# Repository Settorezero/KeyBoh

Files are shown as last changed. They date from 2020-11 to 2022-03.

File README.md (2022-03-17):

# KeyBoh

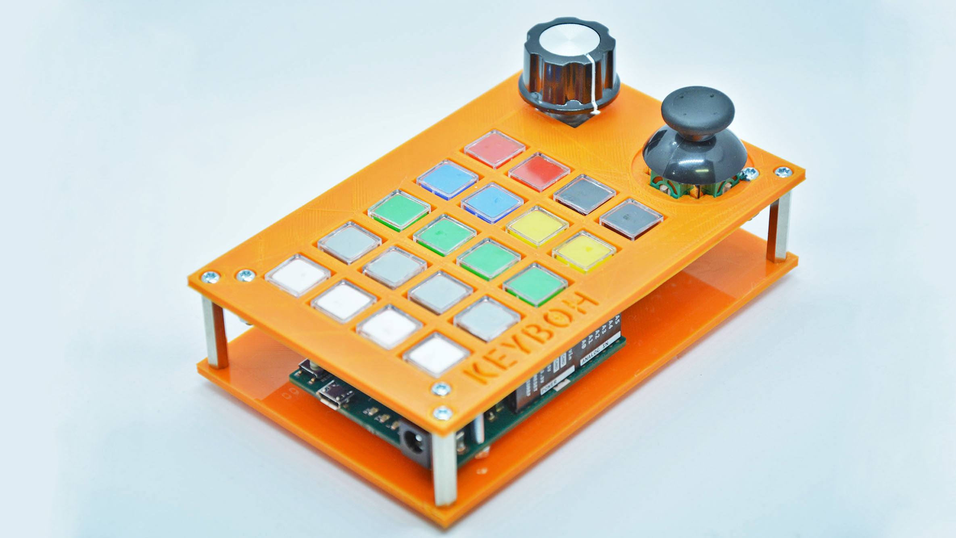
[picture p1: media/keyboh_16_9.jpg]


KeyBoh is an Arduino Leonardo shield for making customizable, cheap, USB keyboards. We love to use the [NicoHood HID Project library](https://github.com/NicoHood/HID) for interfacing the whole thing to a Computer. It's very cheap because uses commonly available 12x12 tactile switches.

## PCB  
PCBWay has the project ready to be manufactured and shipped. Making the PCB on PCBWay will support our work!  
You need to subscribe to PCBWay first using [this invite link](https://www.pcbway.com/setinvite.aspx?inviteid=355653&from=settorezero2020). Then you'll have a bonus of $5 for PCB Manufacturing.   
Once subscribed to PCBWay you can let them make you the PCB [from the shared project page](https://www.pcbway.com/project/shareproject/KeyBoh_Shield.html).
[Gerbers](./gerbers) are provided anyway.

## Enclosure
In the [STL folder](./stl) are located the two panels you can 3Dprint by yourself. Then you can assemble the Keyboh as showed in the pictures using 4x 24mm F/F  and 4x M/F 6mm hex spacers + 12x M3 6mm screws and 4 3M bolts.

## Code examples
See in the [Arduino folder](./arduino) for code examples. We're currently working to a multi-predefined configurable keyset for various applications, so stay tuned.  

## Informations
See the [NicoHood HID Project library](https://github.com/NicoHood/HID) for knowing how library works and example.
In the [keys.txt](./docs/keys.txt) document are reported the names for the keys of the keyboard as used by NicoHood library.

## Connection table
(To do)
In the meanwhile look at schematic in the [docs folder](./docs)

## Can I use keyboh with other boards?
Keyboh is designed for the Arduino __Leonardo__ using his own USB features for making USB devices you can use on the computer or any device recognizes HID devices (even if on cellphone).

### Keyboh on Arduino UNO ?
You can use Keyboh on the Arduino UNO if you want to control remote devices through the UART: you can connect an external device simply connecting the UART using wires or you can attach a Bluetooth or an XBee module, or an ESP8266 but be always aware of the voltage levels! There is the possibility to have a voltage divider only on the Arduino RX but connecting an ESP8266 requires a voltage divider on the TX.  

You can use Keyboh on the Arduino UNO also for USB communication using the [HoodLoader by NicoHood](https://github.com/NicoHood/HoodLoader2). This project is made for reprogramming the 16U2, used on the UNO as serial/USB bridge, and use it for USB custom purposes. We've still not used that feature so please read the documentation of this library.

Since the Leonardo has separate `SDA` and `SCL` lines while the UNO has `SDA` and `SCL` shared with `A4` and `A5`, using the shield on the UNO will make not available I2C lines, or you may not use the joystick (connected to A4 and A5) freeing those two pins for using them for I2C.  

### Keyboh on other boards
You can use the shield on other development boards connecting wires on pads: the silkscreen will help a lot.  
You can also saw off the PCB part with encoder and joystick: a part of soldering pads will be anyway available for reconnecting the two separate pcbs or for connecting them through wires.

## Warnings!!
Since keymatrix is implemented __without protection diodes on pushbuttons__, is no safe press more than 1 button on the same row at a time: this bring to a momentary short-circuit since 2 or more columns are connected together. Usually this is not a big problem since the duration of the short is very small due to column scan, but is better not doing this. In the next revision we'll add the protection diodes.

## Bad Coding leads to problems!
First of all: Always remember to put a `Keyboard.releaseALL()` or `Keyboard.relese([KEY])` after `Keyboard.press` instructions or the keys will remain pressed forever causing a lot of problems!

A very big problem is this: you write some wrong instructions so the keyboard cycles some keys indefinitely (ore some keys are always pressed) and then, since those keys affects the Arduino IDE functions, you may be not able to reprogram the board. In this case a thing you can do is detach the Arduino Leonardo, then see in the Control Panel which devices are connected, then you attach the Leonardo and you will see new devices (example: _HID Keyboard_), in the panel you can try to disinstall the new device (<kbd>Mouse right click</kbd> - <kbd>Uninstall</kbd>) but you need to do this very fast.

In worst cases you can reprogram the Leonardo with a clean sketch on the ISP connector using another Arduino as ISP programmer.

Another problem can be _board not recognized_ from Arduino IDE even if the board is working and the selected serial port is right. In this case try to disconnect and reconnect the USB cable or pressing the Leonardo <kbd>reset</kbd> button after you've pressed the IDE button for the sketch upload.

## Notes for an ipothetical next PCB revision
- Add protection diodes on keymatrix switches
- Add circuitry for hardware debounce, on the encoder mainly
- Add voltage divider also on UART TX
- Use the Arduino micro instead of Leonardo (more compact) ?

## Links
- [more pictures of KeyBoh](https://photos.app.goo.gl/CL2jDvoLArWxuAqx8)
- [video example: usage on Photoshop](https://www.instagram.com/tv/CJuXJ9UKTim/)
- [video example: usage with commercial robot](https://www.instagram.com/p/CJzhHA2K29V/)

## Sharings
Since we love when others share our projects, here are linked pages who shared the project.  
Those links can be useful since people make also questions commenting on social posts and we try to give answers directly.

- [Arduino on IG](https://www.instagram.com/p/CIPJXs_j-tg/)
- [Arduino on TW](https://twitter.com/arduino/status/1333078330598363136)
- [Arduino on FB](https://www.facebook.com/official.arduino/posts/5567229216636685)
- [PCBWay on IG](https://www.instagram.com/p/CINa9Nnra6t/)
- [PCBWay on TW](https://twitter.com/PCBWayOfficial/status/1333344888537026561)
- [Microchip on IG](https://www.instagram.com/p/CIRuX1qnB_U/)
- [Microchip on TW](https://twitter.com/MicrochipMakes/status/1333442492117737475)
- [Microchip on FB](https://www.facebook.com/MicrochipMakes/posts/3820599841292022)
- [Hackster](https://www.hackster.io/news/keyboh-is-an-open-source-arduino-leonardo-shield-for-making-custom-usb-keyboards-208a930cc3f5)

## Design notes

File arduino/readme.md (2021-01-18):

## KeyBoh Firmwares

[Keytest](./keytest)  
Output values of buttons, encoder and thumbstick on the serial port. 
Only for testing purposes, to be sure every component on PCB works. So this sketch has no HID functions.

[Example](./example)  
Thumbstick and encoder used as mouse functions. 
Maybe you can would use this sketch as _skeleton_ for your projects

[Photoshop](./photoshop)  
Favourite commands for Adobe Photoshop.

[Inkscape](./inkscape)  
Favourite commands for Inkscape.

[Rasptank](./rasptank)  
Commands for Cyb3rn0id version of Adeept Rasptank control interface.

[Multimedia](./multimedia)  
Controls for music/video players and Browser

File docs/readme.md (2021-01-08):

### Keyboh Documents

- [BOM](keyboh_bom.txt)
- [Schematic](keyboh_schematic.png)
- [Keys names for Nicohood Library](keys.txt)

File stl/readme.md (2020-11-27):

# KeyBoh 3D Files for 3d-Printing 
This folder contains parts to be 3D-printed. I Reccomended [Sunlu PLA+](https://amzn.to/3aG5V7i) filament.  

## Printer settings
- Infill: 25%
- Support: NO
- Layer Height: 0.2mm

## Parts
- [Top panel](keyboh_top.stl)
- [Bottom panel](keyboh_bottom.stl)

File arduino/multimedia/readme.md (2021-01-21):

### Example

Multimedia + Browser controls. Tested on Foobar2000, VLC and Youtube.
Files `.docx` and `.pdf` are for printing stickers to be applied between keycaps and transparent lid.
You can edit the `.docx` and use it as template for making your own graphics.
[Icons8](https://github.com/icons8) has a lot of colored icons.

#### Configuration

ENCODER
- <kbd>Clockwise Rotation</kbd>: Volume UP
- <kbd>Counter-Clockwise Rotation</kbd>: Volume Down
- <kbd>Button</kbd>: Mute/No Mute

THUMBSTICK 
- <kbd>X axis</kbd>: Multimedia Rewind / Fast Forward [*]
- <kbd>Y axis</kbd>: Mouse Scroll Up / Scroll Down [**]
- <kbd>Button</kbd>:

[*] In VLC Media Player this control is used for setting the reproduction speed, so if you release the stick, speed setting will persist.  
In Foobar2000 works as expected: releasing the stick will reset to the normal speed.  
  
[**] In some programs (ex.: VLC Media Player), Mouse Scroll Up/Down is used for Volume Control.  
On Foobar2000 will scroll between tracks in a playlist.

ROW 1
- <kbd>Button 1</kbd>: Multimedia Play/Pause
- <kbd>Button 2</kbd>: Multimedia Stop
- <kbd>Button 3</kbd>: Multimedia Previous media in the playlist
- <kbd>Button 4</kbd>: Multimedia Next media in the playlist
- <kbd>Button 5</kbd>: Multimedia Record

Note:
Not all programs uses Record button. In VLC Works.  
  
I tried Audacity, but seems Audacity don't use any multimedia button.  
  
On Youtube only play/pause and stop works. Next/Previous don't work even you're in a playlist. In Youtube if you press Stop, video don't restarts if you press play on the Keyboh: you must click play on the video: I don't know if it's a problem of the browser or youtube.

ROW 2
- <kbd>Button 6</kbd>: Consumer Open Browser / Go to Home page
- <kbd>Button 7</kbd>: Consumer Browser Refresh
- <kbd>Button 8</kbd>: Consumer Browser Back
- <kbd>Button 9</kbd>: Consumer Browser Forward
- <kbd>Button 10</kbd>: 

ROW 3
- <kbd>Button 11</kbd>: 
- <kbd>Button 12</kbd>: 
- <kbd>Button 13</kbd>: 
- <kbd>Button 14</kbd>: 
- <kbd>Button 15</kbd>: 

ROW 4
- <kbd>Button 16</kbd>: 
- <kbd>Button 17</kbd>:
- <kbd>Button 18</kbd>: 
- <kbd>Button 19</kbd>: 
- <kbd>Button 20</kbd>:

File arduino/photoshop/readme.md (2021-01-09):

### Functions for Adobe Photoshop

You can use this sketch for controlling Adobe Photoshop.  
I've put my favourite commands, you can change the sketch for implementing what you want.

#### Configuration

ENCODER
- <kbd>Clockwise Rotation</kbd>: Zoom IN (CTRL +)
- <kbd>Counter-Clockwise Rotation</kbd>: Zoom OUT (CTRL -)
- <kbd>Button</kbd>: Alternate between Zoom Fit (CTRL 0) / Zoom 100% (CTRL 1)
>  These same commands are used also in a lot of other programs such as web browsers

THUMBSTICK 
- <kbd>X axis</kbd>: PAN Left/Right (SHIFT CTRL PGUP / SHIFT CTRL PGDN)
- <kbd>Y axis</kbd>: PAN up/down (SHIFT PGUP/SHIFT PGDN)
- <kbd>Button</kbd>: Change screen Mode (toggle fullscreen) (F)

ROW 1
- <kbd>Button 1</kbd>: Save As (CTRL SHIFT S)
- <kbd>Button 2</kbd>: Undo (CTRL ALT Z)
- <kbd>Button 3</kbd>: Show the INFO window (F8) (useful because give the pointer coordinates)
- <kbd>Button 4</kbd>: Resize (CTRL ALT I)
- <kbd>Button 5</kbd>: Change Canvas size (CTRL ALT C)

ROW 2
- <kbd>Button 6</kbd>: Alternate between Normal and Precision CrossHair (CAPS/LOCK)
- <kbd>Button 7</kbd>: Pointer/move (V)
- <kbd>Button 8</kbd>: Switch Between Rapid Selection/Magic Wand (SHIFT W)
- <kbd>Button 9</kbd>: Rectangular Select (M)
- <kbd>Button 10</kbd>: Switch Between Lasso types (SHIFT L)

ROW 3
- <kbd>Button 11</kbd>: Crop (C)
- <kbd>Button 12</kbd>: Eraser (E)
- <kbd>Button 13</kbd>: Switch Between Brush/Pencil/Color change/Mix Color (SHIFT B)
- <kbd>Button 14</kbd>: Horizontal Text (T)
- <kbd>Button 15</kbd>: Switch Background and Foreground colors (X)

ROW 4
- <kbd>Button 16</kbd>: Invert (CTRL I)
- <kbd>Button 17</kbd>: Black and White (CTRL ALT SHIFT B)
- <kbd>Button 18</kbd>: Color balance (CTRL B)
- <kbd>Button 19</kbd>: Brush window (F5)
- <kbd>Button 20</kbd>: Show/Hide Grid (CTRL ,)

### Notes
- Removing the comment at row `#define MAC` will make the program use the Mac key <kbd>⌘</kbd> instead of the Windows/Linux <kbd>LEFT CTRL</kbd> where CTRL or ⌘ are required. I don't have a MAC so those functions are untested for the MAC.
- Instead of the ALT on MAC is used the <kbd>OPTION</kbd> button. I didn't found this button in the library, maybe the is the same of ALT?
- Every click on the encoder button alternate between Zoom Fit (adapt image to the monitor) and Zoom 100% (real dimensions). After a zoom command the first press of encoder will be resetted to Zoom fit (flag `zoomfit`).

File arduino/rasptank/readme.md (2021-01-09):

### Functions for Adeept Rasptank

You can use this sketch for controlling the Rasptank using the [package provided by CyB3rn0id](https://www.github.com/cyb3rn0id/adeept_rasptank).  
More info about Adeept Rasptank in [this article](https://www.tinyurl.com/rasptank).
This sketch is different than those used for software shortcuts since a key must be kept pressed until the user release it and you must release only that key, not all. 

#### Configuration

ENCODER
- not used

THUMBSTICK 
- <kbd>X axis</kbd>: Move Forward / Backward (W / S)
- <kbd>Y axis</kbd>: TUrn Left / Right (A / D)
- <kbd>Button</kbd>: Not used

ROW 1
- <kbd>Button 1</kbd>: Open Hand (O)
- <kbd>Button 2</kbd>: Close Hand (P)
- <kbd>Button 3</kbd>: 
- <kbd>Button 4</kbd>: 
- <kbd>Button 5</kbd>: 

ROW 2
- <kbd>Button 6</kbd>: Rotate Hand Clockwise (K)
- <kbd>Button 7</kbd>: Rotate Hand Counter-Clockwise (L)
- <kbd>Button 8</kbd>: 
- <kbd>Button 9</kbd>: 
- <kbd>Button 10</kbd>: 

ROW 3
- <kbd>Button 11</kbd>: Move Arm Forward (N)
- <kbd>Button 12</kbd>: Move Arm Backward (M)
- <kbd>Button 13</kbd>: 
- <kbd>Button 14</kbd>: 
- <kbd>Button 15</kbd>: 

ROW 4
- <kbd>Button 16</kbd>: Move Camera and Ultrasonic sensor Upward (R)
- <kbd>Button 17</kbd>: Move Camera and Ultrasonic sensor Downward (F)
- <kbd>Button 18</kbd>: 
- <kbd>Button 19</kbd>: 
- <kbd>Button 20</kbd>:

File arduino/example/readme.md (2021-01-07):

### Example

You can use this sketch as _skeleton_ for your simple projects.  

Keyboh Configuration:
- Buttons from 1 to 19 are not used
- Button 20 used for switching between 2 mouse speeds
- Thumbstick: moves mouse pointer
- Thumbstick click: mouse left button
- Encoder: mouse scroll
- Encoder click: mouse right button

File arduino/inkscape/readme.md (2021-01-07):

### Functions for Inkscape

You can use this sketch for controlling [Inkscape](https://inkscape.org/).  
I've put my favourite commands, you can change the sketch for implementing what you want.  
All Inkscape commands, shortcuts and functions are [listed here](https://inkscape.org/sk/doc/keys.html).

#### Configuration

ENCODER
- <kbd>Clockwise Rotation</kbd>: Zoom IN (+)
- <kbd>Counter-Clockwise Rotation</kbd>: Zoom OUT (-)
- <kbd>Button</kbd>: Alternate between Zoom Fit (5) / Zoom 100% (1)

> Some people complains about they cannot write <kbd>+</kbd> and <kbd>-</kbd> in the Text areas because those keys are associated with the zoom function and so by pressing them the zoom changes and no signs are written.  
The key associated with the zoom functions are <kbd>+</kbd> and <kbd>-</kbd> located on the Numeric Keypad! The <kbd>+</kbd> and <kbd>-</kbd> on the keyboard (<kbd>+</kbd> on the same key where are located also <kbd>*]}</kbd> and <kbd>+</kbd> on the same key where is located the <kbd>underscore</kbd>) don't affect the zoom function.

THUMBSTICK 
- <kbd>X axis</kbd>: PAN Left/Right (SHIFT Mouse SCRLDN / SHIFT Mouse SCRLUP)
- <kbd>Y axis</kbd>: PAN up/down (Mouse SCRLUP/Mouse SCRLDN)
- <kbd>Button</kbd>: Go to page center without changing zoom (CTRL 4)

ROW 1
- <kbd>Button 1</kbd>: Save As (CTRL SHIFT s)
- <kbd>Button 2</kbd>: Undo (CTRL z)
- <kbd>Button 3</kbd>: Create Rectangle (r)
- <kbd>Button 4</kbd>: Create Ellipses (e)
- <kbd>Button 5</kbd>: Create Poligon and Stars (KEYPAD *)

ROW 2
- <kbd>Button 6</kbd>: Arrow (selector) (F1)
- <kbd>Button 7</kbd>: Node Selector (F2)
- <kbd>Button 8</kbd>: Draw Lines (b)
- <kbd>Button 9</kbd>: Draw Hand-free lines (p)
- <kbd>Button 10</kbd>: Insert Text (t)

ROW 3
- <kbd>Button 11</kbd>: Dropper (d)
- <kbd>Button 12</kbd>: Paint Bucket (u)
- <kbd>Button 13</kbd>: Eraser (SHIFT e)
- <kbd>Button 14</kbd>: Ruler (m)
- <kbd>Button 15</kbd>: 

ROW 4
- <kbd>Button 16</kbd>: Resize page to current selection, or to the drawing if nothing is selected (SHIFT CTRL r)
- <kbd>Button 17</kbd>: Open the window Align and Distribute (SHIFT CTRL a)
- <kbd>Button 18</kbd>: Open the window Fill and Stroke (SHIFT CTRL f)
- <kbd>Button 19</kbd>: Export to PNG (SHIFT CTRL e)
- <kbd>Button 20</kbd>: Toggle Windows (F12)

### Notes
- Every click on the encoder button alternate between Zoom Fit (adapt image to the monitor) and Zoom 100% (real dimensions). After a zoom command the first press of encoder will be resetted to Zoom fit (flag `zoomfit`).

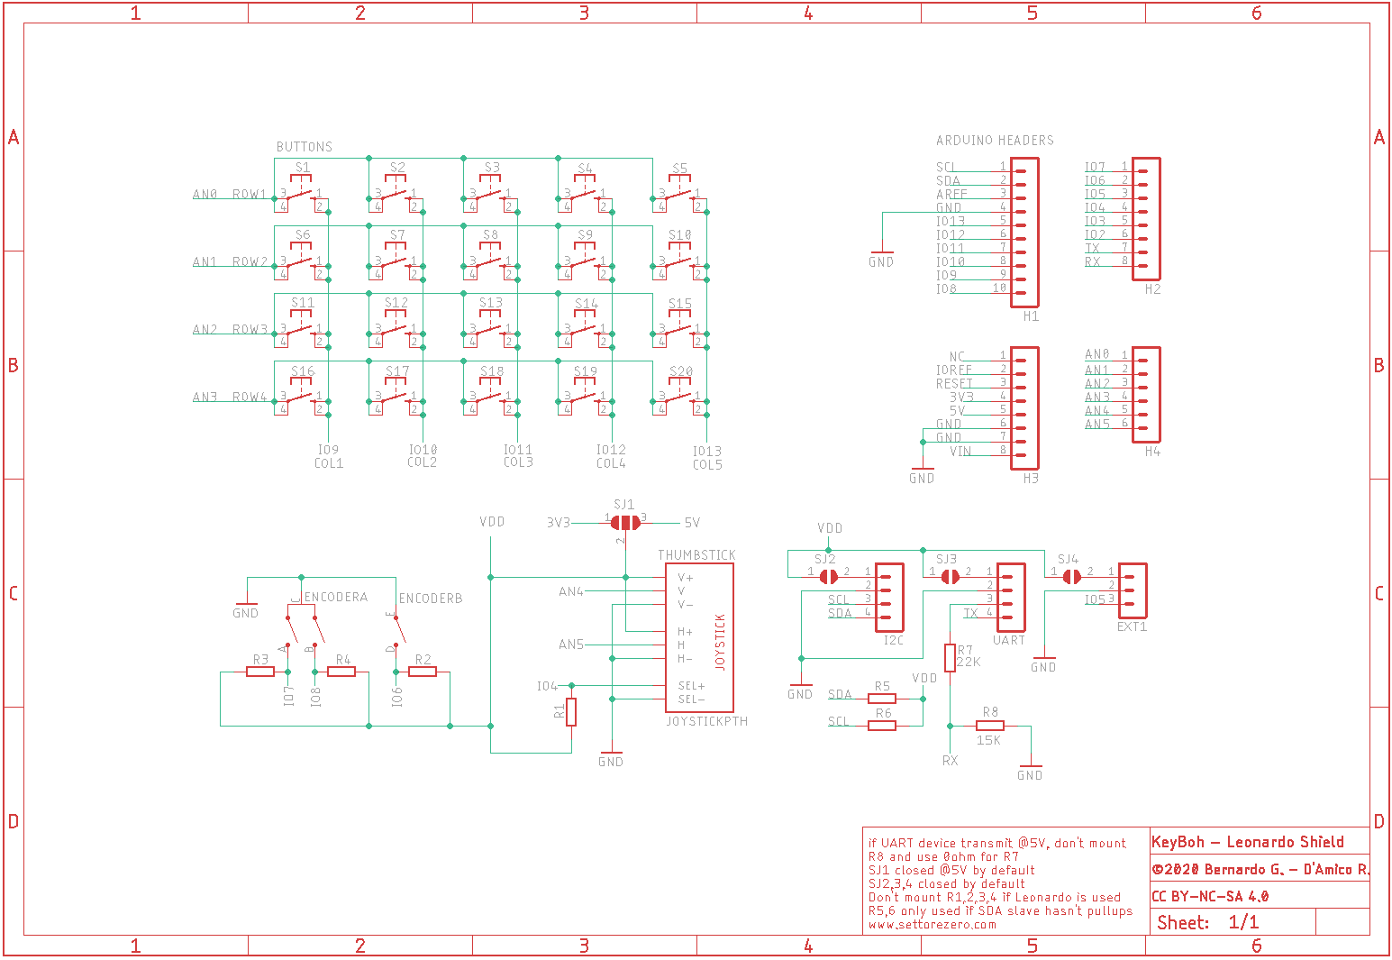
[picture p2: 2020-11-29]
docs/keyboh_schematic.png

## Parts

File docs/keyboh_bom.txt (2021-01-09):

KEYBOH Bill Of Materials

1) Component to be soldered on the PCB
2) External components

---------------------------------------------------

1 - Component to be soldered on PCB

Part			Value											Notes
S1 to S20		tactile switch 12mm								Square keycap if you'll 3d print the provided faceplate
R1				leave empty										10K for devices without integrated pull-up resistors
R2				leave empty										10K for devices without integrated pull-up resistors
R3				* 1nF ceramic capacitor							10K resistor for devices without integrated pull-up resistors
R4				* 1nF ceramic capacitor							10K resistor for devices without integrated pull-up resistors
R5				as needed by I2C if you use it					4.7K to 10K depending I2C slave requirements
R6				as needed by I2C if you use it					4.7K to 10K depending I2C slave requirements
R7				** close or 22K									close if you use original Arduino Leonardo
R8				** empty or 15K									leave empty if you use original Arduino Leonardo
ENCODER			rotary encoder
THUMBSTICK		PS2-like analog thumbstick
H1				male pinheader 10pin							Arduino header - solder on top
H2				male pinheader 8pin								Arduino header - solder on top
H3				male pinheader 8pin 							Arduino header - solder on top
H4				male pinheader 6pin 							Arduino header - solder on top
UART			male pinheader right angle 4pin                 Optional
I2C				male pinheader right angle 4pin                 Optional
EXT1			male pinheader right angle 3pin                 Optional

* Those 2 placeholders was originally intended for mounting resistors when using keyboh with microcontrollers don't have internal pull-up resistors. With Arduino Leonardo resistors are not needed and you must mount 1nF ceramic capacitors for improving the encoder response. Mounting capacitors and using the provided debounce functions in the examples, the response of the encoder is very good

** Those 2 resistors are used only in the case you use an Arduino Compatible board running at 3.3V and the device on UART connector
works at 5V, in that case two resistors forms a voltage divider that consent to receive a 3.3V signal on RX pin of Arduino.
If you use a 3.3V Arduino Leonardo or other device, you must also change the SJ1 solder jumper setting, and eventually disconnect
also the SJ2, SJ3 and SJ4 solder jumpers or simply don't use the 5V pin if not needed

2 - External components

1x	Arduino Leonardo original board

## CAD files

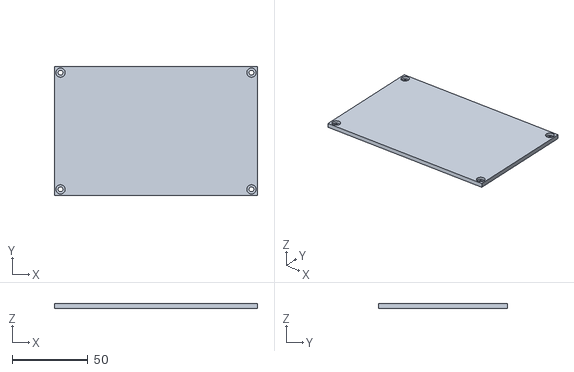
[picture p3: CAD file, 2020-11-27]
stl/keyboh_bottom.stl
134.0 x 85.0 x 3.00

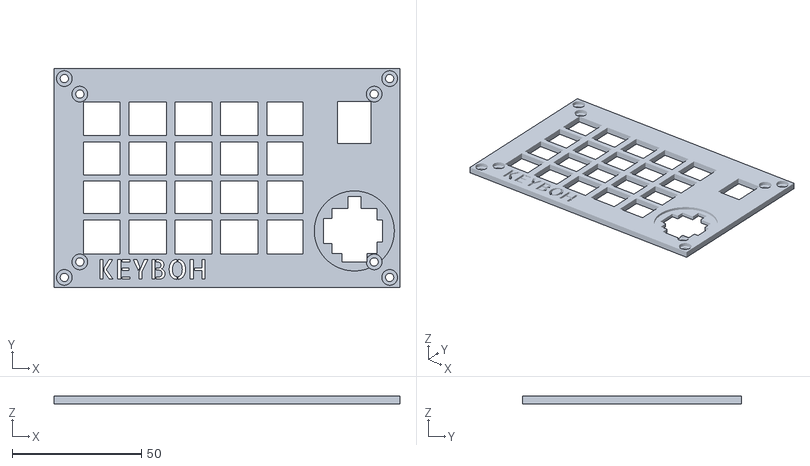
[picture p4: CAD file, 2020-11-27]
stl/keyboh_top.stl
134.0 x 85.0 x 3.00

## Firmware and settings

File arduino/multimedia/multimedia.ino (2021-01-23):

/* 
 * KeyBoh
 * https://www.github.com/settorezero/keyboh
 * (C)2020 Giovanni Bernardo (Cyb3rn0id), Roberto D'Amico (Bobboteck)
 * https://www.settorezero.com
 *
 * Multimedia:
 * Thumbstick: will move the mouse pointer
 * Click on Thumbstick button: left mouse click
 * Encoder rotation: mouse scroll
 * Click on Encoder button: right mouse click
 * Button 20: switch between 2 mouse speeds
 */

#include "HID-Project.h" // HID-Project library by Nico-Hood

// keypad
int row[]={A0,A1,A2,A3};    // matrix keypad - rows 
int col[]={9,10,11,12,13};  // matrix keypad - columns
// encoder
#define ENC_BTN   6
#define ENC_A     7
#define ENC_B     8
// thumbstick
#define STICK_BTN 4
#define STICK_X   A5
#define STICK_Y   A4

// remove comment if you want to invert encoder behaviour
#define ENCODER_INVERT

// improve encoder readings checking for two consecutive ticks at same level
// pro: more accurate against bouncing, con: encoder speed slower
//#define ENCODER_DOUBLECHECK

// milliseconds for encoder check
// after a good check, will attend those ms for re-check encoder ignoring interrupts
#define ENCODER_ANTIBOUNCE_MS 30

void setup()
  {
  uint8_t i=0;
  // rows setup
  for (i=0; i<4; i++)
    {
    pinMode(row[i], INPUT_PULLUP);
    }
  // columns setup
  for (i=0; i<5; i++)
    {
    pinMode(col[i], OUTPUT);
    digitalWrite(col[i], HIGH);
    }
  // encoder and thumbstick setup  
  pinMode(ENC_A, INPUT_PULLUP);
  pinMode(ENC_B, INPUT_PULLUP);
  pinMode(ENC_BTN, INPUT_PULLUP);
  pinMode(STICK_BTN, INPUT_PULLUP);
  // encoder interrupt
  attachInterrupt(digitalPinToInterrupt(ENC_A), encoderTick, CHANGE); // Pulse interrupt
  // HID peripherals initialization
  Keyboard.begin();
  Mouse.begin();
  Consumer.begin(); // used for multimedia buttons
  //Gamepad.begin();
  }

void loop()
  {
  // check pressed button on the 5x4 matrix
  // buttons are numbered from 1 to 20 as on the PCB
  // the number of the button pressed is (column+1)+(row*5)
  static uint8_t pressed_button=0; // pressed button on matrix keypad from 1 to 20, 0=no button pressed
  static long last_T; // used for giving some delay to mouse movement
  // keyboard scan
  for(uint8_t c=0; c<5; c++) // column scan
      {
      digitalWrite(col[c], LOW);
      for(uint8_t r=0; r<4; r++) // row scan
         {
         if(digitalRead(row[r])==LOW)
            {
            delay(20); // antibounce
            if(digitalRead(row[r])==LOW)
              {
              pressed_button=(c+1)+(r*5);
              while(digitalRead(row[r])==LOW); // stay until button released
              }
            }
         } // \row scan
       digitalWrite(col[c], HIGH);
       } // \column scan

	  // a button is pressed, recall the associated function
    if (pressed_button>0) 
      {
        do_keypad_stuff(pressed_button);
        pressed_button=0;
      }
    
    // check encoder button
    if (digitalRead(ENC_BTN)==LOW)
      {
      delay(20);
      if (digitalRead(ENC_BTN)==LOW)
        {
         do_encoder_button_stuff(); 
         while(digitalRead(ENC_BTN)==LOW);
        }
      }

    // check thumbstick button
    if (digitalRead(STICK_BTN)==LOW)
      {
      delay(20);
      if (digitalRead(STICK_BTN)==LOW)
        {
         do_thumbstick_button_stuff();
         while(digitalRead(STICK_BTN)==LOW);
        }
      }

   // check analog thumbstick axis
   int16_t x=analogRead(STICK_X);
   int16_t y=analogRead(STICK_Y);
   if (millis()-last_T>100)
      {
      do_thumbstick_analog_stuff(x,y);
      last_T=millis();
      }
   } // \loop

// encoder interrupt
void encoderTick()
  {
  static long t=millis();
  static int8_t m=0; // movement: 0=no movement, 1=clockwise, -1=counter-clockwise
  static int8_t c=0; // the tick will be checked two consecutive times, this will count the consecutive times
  if (t>millis()) t=millis(); // millis() rollover
  if (millis()-t<ENCODER_ANTIBOUNCE_MS) return; // to few time passed, maybe is a bounce
  c++; // a tick has occurred
  if (digitalRead(ENC_A)==digitalRead(ENC_B)) 
    {
    #ifdef ENCODER_DOUBLECHECK
    
      if (c==1) m=1; // first tick with clockwise movement
      if (c==2) // second tick
        {
        if (m==1) // the movement is still clockwise?
          {
          #ifdef ENCODER_INVERT
            do_encoder_counterclockwise_stuff();
          #else
            do_encoder_clockwise_stuff();
          #endif
          }
        c=0;
        m=0;
        }
    
    #else
        
        #ifdef ENCODER_INVERT
          do_encoder_counterclockwise_stuff();
        #else
          do_encoder_clockwise_stuff();
        #endif
        c=0;
    #endif
    }
  else // movement is counter-clockwise
    {
    #ifdef ENCODER_DOUBLECKECK
      
      if (c==1) m=-1;
      if (c==2)
        {
        if (m==-1)
          {
          #ifdef ENCODER_INVERT
            do_encoder_clockwise_stuff();
          #else
            do_encoder_counterclockwise_stuff();
          #endif     
          }
        c=0;
        m=0;
        }
    #else
      
        #ifdef ENCODER_INVERT
          do_encoder_clockwise_stuff();
        #else
            do_encoder_counterclockwise_stuff();
        #endif     
        c=0;
        
    #endif
    }
  t=millis(); // last time we checked
  }

//********************************************************************************************************************
// Keypad functions
//******************************************************************************************************************** 
void do_keypad_stuff(uint8_t pb)
  {
  switch (pb)
    {
    // ROW 1
    case 1:
      Consumer.write(MEDIA_PLAY_PAUSE);
      break;

    case 2:
      Consumer.write(MEDIA_STOP);
      break;

    case 3:
      Consumer.write(MEDIA_PREVIOUS);
      break;

    case 4:
      Consumer.write(MEDIA_NEXT);
      break;

    case 5:
      Consumer.write(MEDIA_RECORD);
      break;

    // ROW 2
    case 6:
      Consumer.write(CONSUMER_BROWSER_HOME);
      break;

    case 7:
      Consumer.write(CONSUMER_BROWSER_REFRESH);
      break;

    case 8:
      Consumer.write(CONSUMER_BROWSER_BACK);
      break;

    case 9:
      Consumer.write(CONSUMER_BROWSER_FORWARD);
      break;

    case 10:
      break;

    // ROW 3
    case 11:
      break;

    case 12:
      break;

    case 13:
      break;

    case 14:
      break;

    case 15:
      break;

    // ROW 4
    case 16:
      break;

    case 17:
      break;

    case 18:
      break;

    case 19:
      break;

    case 20:
    
    default:
       return;
      break;
    }
  return;
  }

//******************************************************************************************************************** 
// ENCODER MOVEMENT
//******************************************************************************************************************** 
void do_encoder_clockwise_stuff(void)
  {
  Consumer.write(MEDIA_VOLUME_UP);
  }

void do_encoder_counterclockwise_stuff(void)
  {
  Consumer.write(MEDIA_VOLUME_DOWN);  
  }

//******************************************************************************************************************** 
// ENCODER BUTTON
//******************************************************************************************************************** 
void do_encoder_button_stuff(void)
  {
  Consumer.write(MEDIA_VOL_MUTE);
  }

//******************************************************************************************************************** 
// THUMBSTICK BUTTON
//******************************************************************************************************************** 
void do_thumbstick_button_stuff(void)
  {
  
  }

//******************************************************************************************************************** 
// THUMBSTICK MOVEMENT
//******************************************************************************************************************** 
void do_thumbstick_analog_stuff(uint16_t x, uint16_t y)
  {
  int8_t dx=0;
  int8_t dy=0;

  // we'll use the analog joystick as a digital joystick
  // so I set a deadband and I'll check only the movement direction, not the movement amount
  if (x>600) dx=-1; // move left
  else if (x<400) dx=1; // move right
  if (y>600) dy=-1; // move up
  else if (y<400) dy=1; // move down
  
  if (dx==1) // right
    {
     Consumer.write(MEDIA_FAST_FORWARD); 
    }
  else if (dx==-1) // left
    {
    Consumer.write(MEDIA_REWIND);   
    }

  if (dy==1) // up
    {
    Mouse.move(0,0,-1);
    }
  else if (dy==-1) // down
    {
    Mouse.move(0,0,1);
    }
  }

// END OF FILE

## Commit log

2020-11-27 added schematic
2020-11-29 changed connector name
2020-11-29 added bom
2021-01-07 added sketch for inkscape
    Added sketch for Inkscape shortcuts
    Corrected some readmes
    [inkscape.ino]
2021-01-08 further info about pcbs
2021-01-09 bom improvements, rasptank example
    Mouting 1nF capacitors instead of R3 and R4 gives very good results if provided debounce routines are used, so corrected some docs.
    Added the example for Adeept Rastank control interface.
    Minor corrections on other sketches
    [example.ino, rasptank.ino]
2021-01-23 more encoder options
    - added possibility to invert encoder behavior
    - added possibility to skip the double check on the encoder ticks
    - encoder delay for antibounce is #defined
    - separated encoder functions
    [multimedia.ino]
